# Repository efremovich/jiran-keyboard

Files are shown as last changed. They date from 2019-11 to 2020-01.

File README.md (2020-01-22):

# Jiran Keyboard
Jiran is a 6x4 matrix ergo keyboard with additional 3 thumb and 1 pinky keys. 



Based on the [Jian](https://github.com/KGOH/Jian-Info) keyboard.

* __Author:__ [t.me/ladniys](https://t.me/ladniys) [u/Ladniy](https://reddit.com/u/Ladniy)
* __Layout:__ [keyboard-layout-editor.com](http://www.keyboard-layout-editor.com/#/gists/0547cd126f61f8c3f76b0a9952901da4)
* __Hardware Availability:__ open source, t.me/ladniys
* __Firmware:__ [QMK](https://github.com/Ladniy/qmk_firmware)
* __Building guide:__ not available yet
* __Parts (BOM):__

| Name | Value | Package | Count | Optional  | Comment |
| :--- | ---: | :--- | ---: | :--- | :--- |
| Pro micro | 5V 16MHz | 17.78x33.02mm | 2 | | |
| Switch | | MX/Alps/Choc | 56 | | |
| Diode | 1N4148 | THT/SMD (SOD-123) | 56 | | |
| Resistor | 4.7k | THT/SMD (0805) | 2 | | Must be placed on the master half |
| TRRS jack | | PJ-320A | 2 | | Optional if you're building only one half  
| Tact switch | | DIP 3X6X4,3mm | 2 |  yes | |
| Mosfet | 2N7002 | SOT-123 | 2 |  yes | Optional for LED's |
| Resistor | 10k | THT/SMD (0805) | 2 |  yes | Optional for LED's |
| Resistor | 330 | THT/SMD (0805) | 56 |  yes | Optional for LED's |
| LED | | THT 1.8mm | 56 |  yes | Optional |

MechChurch (https://t.me/s/mechchurch) Supported by [MechChurch](https://t.me/s/mechchurch) community

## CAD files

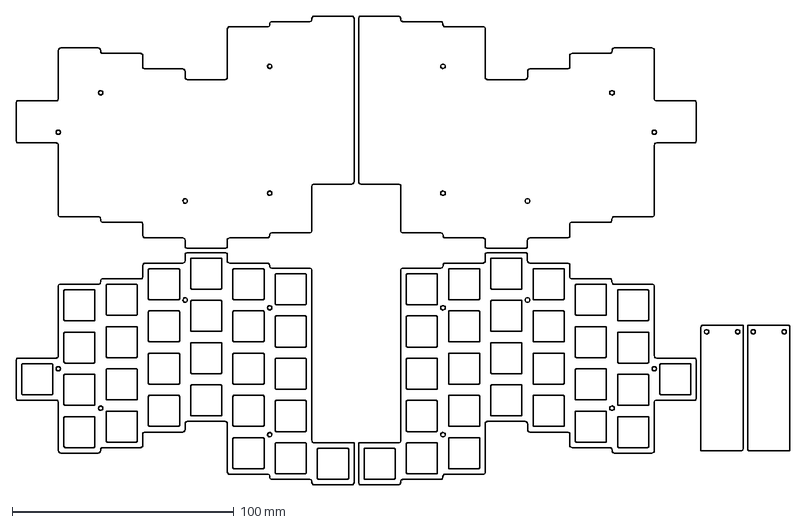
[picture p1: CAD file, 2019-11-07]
Case/Case.dxf
348.8 x 211.3 mm

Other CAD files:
Case/Case.dwg

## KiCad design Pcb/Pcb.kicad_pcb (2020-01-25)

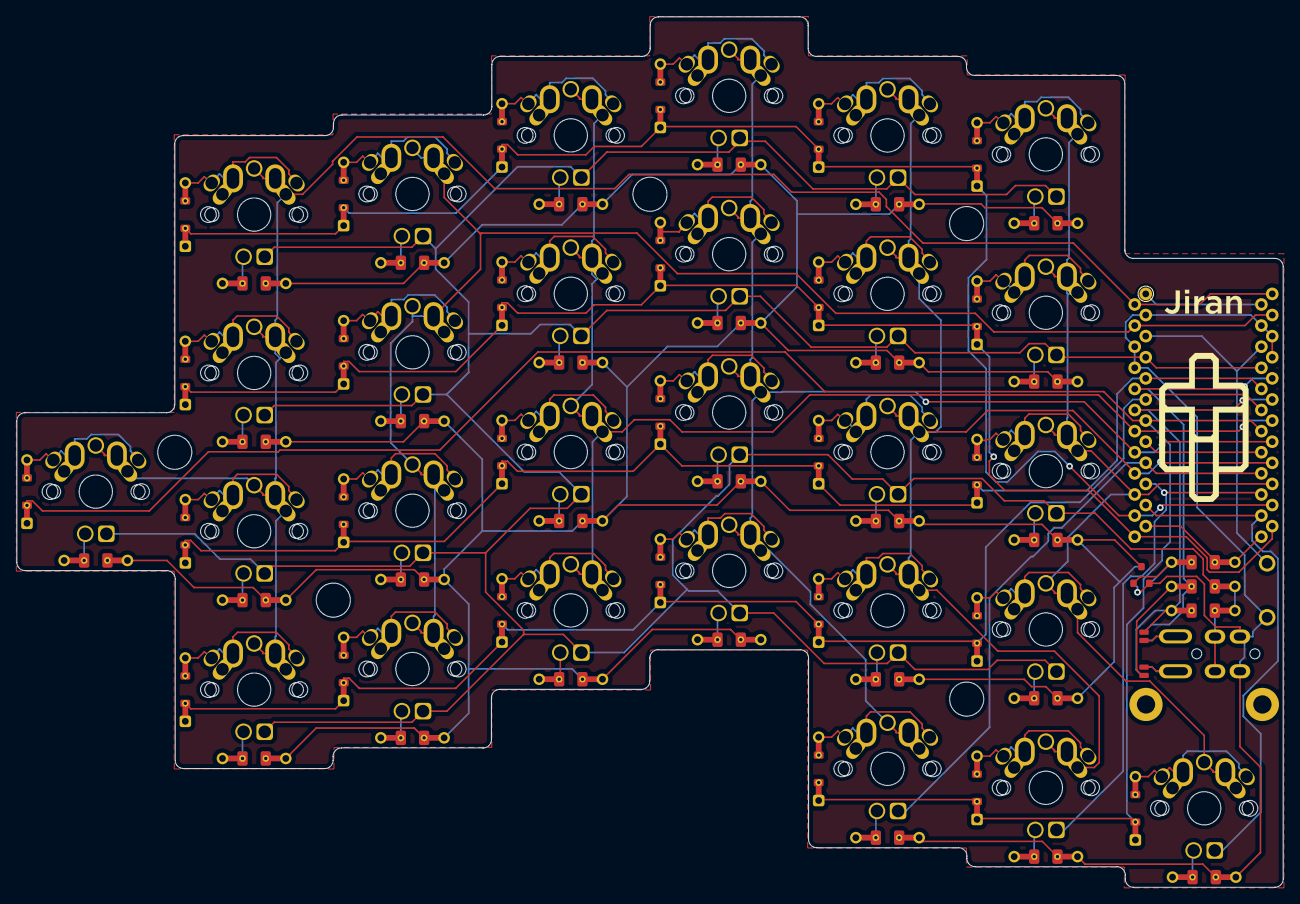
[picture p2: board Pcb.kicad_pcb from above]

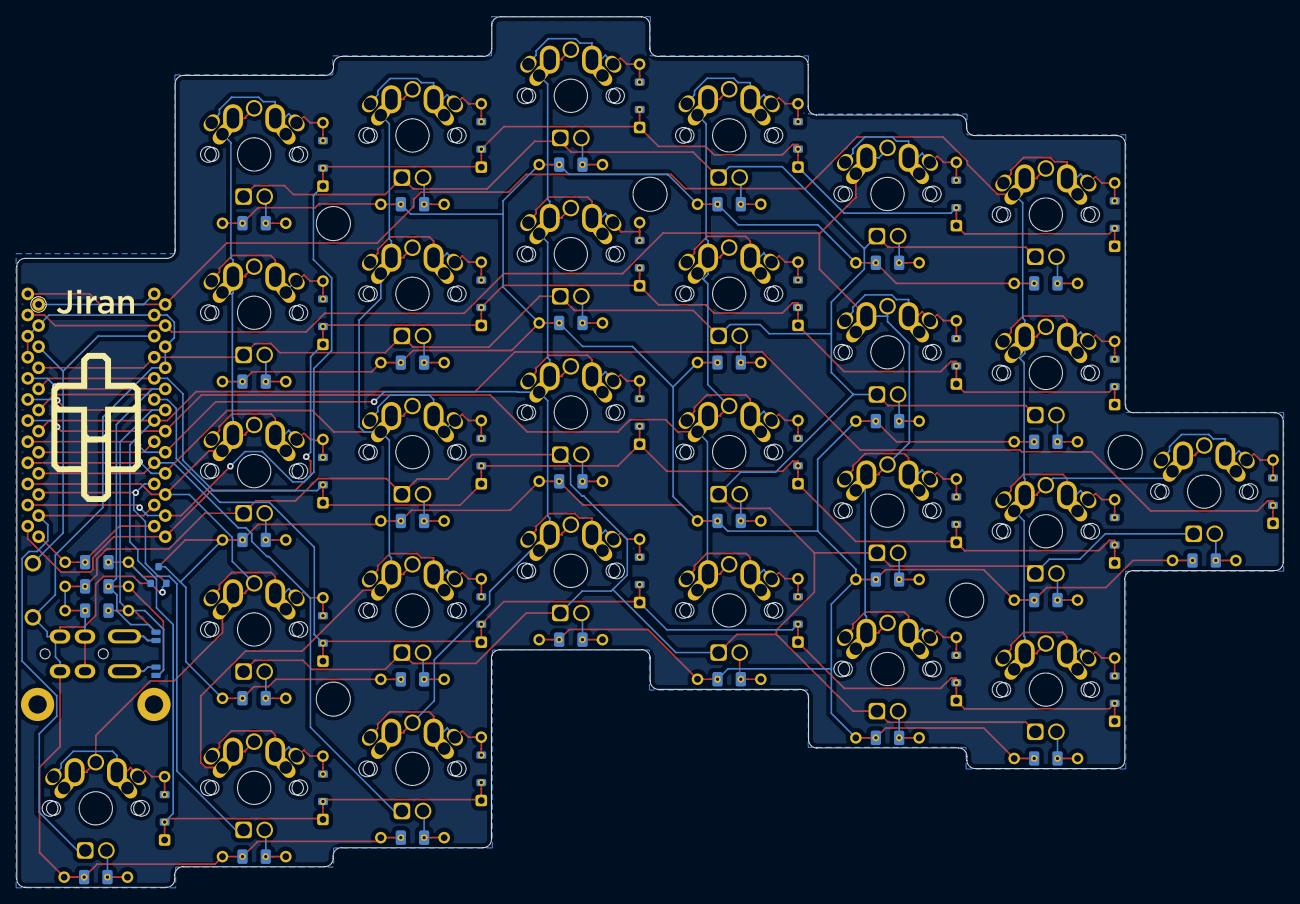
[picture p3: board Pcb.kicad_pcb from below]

Board: 2 copper layers, 152.3 x 104.7 mm, 132 parts (3 on the bottom side), 80 nets.

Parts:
D1, D2, D3, D4, D5, D6, D7, D8, D9, D10, D11, D12, D13, D14, D15, D16, D17, D18, D19, D20, D21, D22, D23, D24, D25, D26, D27, D28: 1N4148; Diode_Hybrid_SOD-123
D29, D30, D31, D32, D33, D34, D35, D36, D37, D38, D39, D40, D41, D42, D43, D44, D45, D46, D47, D48, D49, D50, D51, D52, D53, D54, D55, D56: LED_Small; LED
G1, G2: LOGO; Silk_Logo_Old
H1, H2, H3, H6, H7: CaseHole; MountHole
H8, H9: CoverHole
J1: TRRS; TRSS_DUAL_THT
JP2, JP3, JP4, JP5: Jumper; jumper
Q1: 2N7002; SOT-23
R1, R2, R3, R4, R5, R6, R7, R8, R9, R10, R11, R12, R13, R14, R15, R16, R17, R18, R19, R20, R21, R22, R23, R24, R25, R26, R27, R28: 330R; Resistor_Hybrid_1205
R29, R30: 4.7k; Resistor_Hybrid_1205
R31: 10k; Resistor_Hybrid_1205
SW1, SW3, SW4, SW5, SW6, SW7, SW8, SW9, SW10, SW11, SW12, SW13, SW14, SW15, SW16, SW17, SW18, SW19, SW20, SW21, SW22, SW23, SW24, SW25, SW26, SW27, SW28: SW_Push; Switch_MxAlpsChoc_MillMax_1u
SW2: SW2; Switch_MxAlpsChoc_MillMax_1u
SW29: SW_Push; Reset_Switch
U1: ProMicro; ProMicro_TwoSide

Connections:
/CAPS: D54.2, U1.16
/LED: R31.2, U1.13
/LEDOut: Q1.3, R1.2, R2.2, R3.2, R4.2, R5.2, R6.2, R7.2, R8.2, R9.2, R10.2, R11.2, R12.2, R13.2, R14.2, R15.2, R16.2, R17.2, R18.2, R19.2, R20.2, R21.2, R22.2, R23.2, R24.2, R25.2
/NUM: D56.2, U1.14
/SCROLL: D55.2, U1.15
/col0: SW1.2, SW7.2, SW13.2, SW19.2, SW25.2, U1.1
/col1: SW2.2, SW8.2, SW14.2, SW20.2, U1.2
/col2: SW3.2, SW9.2, SW15.2, SW21.2, U1.7
/col3: SW4.2, SW10.2, SW16.2, SW22.2, SW26.2, U1.8
/col4: SW5.2, SW11.2, SW17.2, SW23.2, SW27.2, U1.9
/col5: SW6.2, SW12.2, SW18.2, SW24.2, SW28.2, U1.10
/rowA: D1.1, D2.1, D3.1, D4.1, D5.1, D6.1, U1.11
/rowB: D7.1, D8.1, D9.1, D10.1, D11.1, D12.1, U1.12
/rowC: D13.1, D14.1, D15.1, D16.1, D17.1, D18.1, U1.20
/rowD: D19.1, D20.1, D21.1, D22.1, D23.1, D24.1, U1.19
/rowE: D25.1, D26.1, D27.1, D28.1, U1.18
GND: J1.B, Q1.2, R26.2, R27.2, R28.2, SW29.2, U1.3, U1.4, U1.23
unnamed: D1.2, SW1.1
unnamed: D2.2, SW2.1
unnamed: D3.2, SW3.1
unnamed: D4.2, SW4.1
unnamed: D5.2, SW5.1
unnamed: D6.2, SW6.1
unnamed: D7.2, SW7.1
unnamed: D8.2, SW8.1
unnamed: D9.2, SW9.1
unnamed: D10.2, SW10.1
unnamed: D11.2, SW11.1
unnamed: D12.2, SW12.1
unnamed: D13.2, SW13.1
unnamed: D14.2, SW14.1
unnamed: D15.2, SW15.1
unnamed: D16.2, SW16.1
unnamed: D17.2, SW17.1
unnamed: D18.2, SW18.1
unnamed: D19.2, SW19.1
unnamed: D20.2, SW20.1
unnamed: D21.2, SW21.1
unnamed: D22.2, SW22.1
unnamed: D23.2, SW23.1
unnamed: D24.2, SW24.1
unnamed: D25.2, SW25.1
unnamed: D26.2, SW26.1
unnamed: D27.2, SW27.1
unnamed: D28.2, SW28.1
unnamed: D29.1, R1.1
unnamed: D30.1, R2.1
unnamed: D31.1, R3.1
unnamed: D32.1, R4.1
unnamed: D33.1, R5.1
unnamed: D34.1, R6.1
unnamed: D35.1, R7.1
unnamed: D36.1, R8.1
unnamed: D37.1, R9.1
unnamed: D38.1, R10.1
unnamed: D39.1, R11.1
unnamed: D40.1, R12.1
unnamed: D41.1, R13.1
unnamed: D42.1, R14.1
unnamed: D43.1, R15.1
unnamed: D44.1, R16.1
unnamed: D45.1, R17.1
unnamed: D46.1, R18.1
unnamed: D47.1, R19.1
unnamed: D48.1, R20.1
unnamed: D49.1, R21.1
unnamed: D50.1, R22.1
unnamed: D51.1, R23.1
unnamed: D52.1, R24.1
unnamed: D53.1, R25.1
unnamed: D54.1, R26.1
unnamed: D55.1, R27.1
unnamed: D56.1, R28.1
unnamed: J1.A, JP2.1, JP3.1
unnamed: J1.D, JP4.1, JP5.1
unnamed: Q1.1, R31.1
RST: SW29.1, U1.22
SCL: JP3.2, JP5.2, R30.2, U1.6
SDA: JP2.2, JP4.2, R29.1, U1.5
VCC: D29.2, D30.2, D31.2, D32.2, D33.2, D34.2, D35.2, D36.2, D37.2, D38.2, D39.2, D40.2, D41.2, D42.2, D43.2, D44.2, D45.2, D46.2, D47.2, D48.2, D49.2, D50.2, D51.2, D52.2, D53.2, J1.C, R29.2, R30.1, U1.21

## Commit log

2019-10-19 Initialize project
    [Pcb.kicad_pcb, Pcb.sch]
2019-10-19 Finished with schematic and footprints
2019-10-19 Started work on pcb
    [Plate.dwg, Plate.dxf]
2019-10-19 PCB update
    [Pcb.kicad_pcb, Plate.dxf]
2019-10-19 PCB route complete
    [Pcb.dsn, Pcb.kicad_pcb]
2019-10-19 Postrout optimization
    [Pcb.kicad_pcb]
2019-10-20 Little Update
    Added hole's for mount, fixed some problems and created 3D design.
    [Plate.dxf]
2019-10-20 Create a 3D case model.
    [Left Case.step]
2019-10-20 Adapted for 3D print case.
    [Pcb.dsn, Pcb.kicad_pcb]
2019-10-21 Adapted for 3D case.
    [Pcb.kicad_pcb]
2019-10-22 Addapted for 3D case
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2019-10-23 Updated Silkscreen
    [Pcb.kicad_pcb]
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2019-10-24 Created gerber files
    [Pcb-B_Cu.gbl, Pcb-B_Mask.gbs, Pcb-B_SilkS.gbo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]
2019-10-24 Created ZIP archive with gerbers
2019-10-26 Created 3D case
    [CaseLeft.step, CaseRight.step, Left Case.step]
2019-10-26 Added file for lasercut for case part
    [UnderPlate.dwg]
2019-10-26 Added file for laser cut for case part
    [UnderPlate.dxf]
2019-10-26 Created and fixed file for laser cut of acrylic case
    [Plate.dwg, Plate.dxf]
2019-10-27 Added STL files for 3D print
    [CaseLeft.stl, CaseRight.stl]
2019-10-27 Removed Tracks
    [Pcb.kicad_pcb]
2019-10-27 Move dot's for other footprints
2019-10-27 Leds was rotated to north side
    [Pcb.kicad_pcb]
2019-10-27 Edited silkscreen
    [Pcb.kicad_pcb]
2019-10-27 Created new name silkscreen
2019-10-27 Created silkscreen for resistors value
2019-10-27 Removed silkscreen for rasistor value
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2019-10-27 Routed and filled
    [Pcb.kicad_pcb]
2019-10-27 Removed old gerbers
    [Pcb-B_Cu.gbl, Pcb-B_Mask.gbs, Pcb-B_SilkS.gbo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]
2019-10-27 Added new gerbers
    [Pcb-B_Cu.gbl, Pcb-B_Mask.gbs, Pcb-B_SilkS.gbo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]
2019-11-02 Fixed bug with I2C resistor's
    [Pcb.sch]
2019-11-02 Unfill zones
    [Pcb.kicad_pcb]
2019-11-02 Deleted track's
    [Pcb.kicad_pcb]
2019-11-02 Moved diode
    [Pcb.kicad_pcb]
2019-11-02 Added support for Choc and Apls switche's
    [Pcb.kicad_pcb]
2019-11-03 Deleted ISP header
    [Pcb.sch]
2019-11-03 Added LED's for lock indication
    [Pcb.sch]
2019-11-03 Changed I2C jack
    [Pcb.sch]
2019-11-03 Updated footprints
    [Pcb.sch]
2019-11-03 Moved some parts
    [Pcb.kicad_pcb]
2019-11-04 Added hole's
    [Pcb.sch]
2019-11-04 Placed hole in correct position
    [Pcb.sch]
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2019-11-04 Update
    Deleted silkscreen, moved jumpers and some components
    [Pcb.kicad_pcb]
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2019-11-04 Redesigned case
    [Plate.dwg, Plate.dxf]
2019-11-04 Created case for Jian mode
    [Plate.dwg, Plate.dxf]
2019-11-04 Update
    Added tracks, edited silkscreen etc.
    [Pcb.kicad_pcb]
2019-11-04 Updated design for both mode
    [Plate.dwg, Plate.dxf]
2019-11-05 Removed catalog with 3D print
    [CaseLeft.step, CaseLeft.stl, CaseRight.step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]
2019-11-05 Unfill all zones
    [Pcb.kicad_pcb]
2019-11-05 Updated jumper footprint
    [Pcb.kicad_pcb]
2019-11-05 Fill all zones
    [Pcb.kicad_pcb]
2019-11-05 Created new gerbers
    [Pcb-B_Cu.gbl, Pcb-B_Mask.gbs, Pcb-B_SilkS.gbo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]
2019-11-06 Import SES file
    [Pcb.kicad_pcb]
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2019-11-09 Update mosfet footprint
    [Pcb.kicad_pcb]
2019-11-09 Add holes for breakway numrow
    [Pcb.kicad_pcb]
2019-11-09 Remove old gerber
    [Pcb-B_Cu.gbl, Pcb-B_Mask.gbs, Pcb-B_SilkS.gbo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]
2019-11-09 Remove old silkscreen footprint
2019-11-09 Add new silkscreen
    [Pcb.kicad_pcb]
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2019-11-10 Route PCB
    [Pcb.dsn, Pcb.kicad_pcb]
2019-11-10 Place track and fill all zones
    [Pcb.kicad_pcb]
2019-11-12 Create gerber files
    [Pcb-B_Cu.gbl, Pcb-B_Mask.gbs, Pcb-B_SilkS.gbo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]
2019-11-12 Add JLC silkscreen mark
    [Pcb.kicad_pcb]
2019-11-12 Move JLC silkscreen mark
    [Pcb.kicad_pcb]
2019-11-12 Create new gerbers files
    [Pcb-B_Cu.gbl, Pcb-B_Mask.gbs, Pcb-B_SilkS.gbo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]
2019-11-12 Create ZIP archive with gerbers
2019-11-13 Add CDR file for Jiran mode case
2019-12-16 Add CDR format file for Jian's mod case
    [Plate_recover.dwg]
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2019-12-18 Update hole footprints
    [Pcb.kicad_pcb]
2019-12-18 Add more break holes
    [Pcb.kicad_pcb]
2019-12-18 Update dsn file for new hole size
    [Pcb.dsn]
2019-12-18 Remove old logo silkscreen
    [Pcb.kicad_pcb]
2019-12-18 Remove hole for Jian mode
    [Pcb.kicad_pcb]
2019-12-18 Move hole for mount
    [Pcb.dsn, Pcb.kicad_pcb]
2019-12-18 Route tracks
    [Pcb.kicad_pcb]
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2019-12-19 Move SOT
    [Pcb.kicad_pcb]
2019-12-19 Move pro micro footprint
    [Pcb.kicad_pcb]
2019-12-20 Update
    Remove old render, edit description, add building and BOM titles
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2019-12-20 Add support millmax socket for swithes
    [Pcb.kicad_pcb, Pcb.sch]
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2019-12-20 Change hole size for spacer
    [Pcb.kicad_pcb]
2019-12-20 Route track
    [Pcb.dsn, Pcb.kicad_pcb]
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2019-12-20 Remove old gerbers
    [Pcb-B_Cu.gbl, Pcb-B_Mask.gbs, Pcb-B_SilkS.gbo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]
2019-12-20 Remove Jian case version
    [Plate.dwg, Plate.dxf]
2019-12-20 Create new gerbers file
    [Pcb-B_Cu.gbl, Pcb-B_Mask.gbs, Pcb-B_SilkS.gbo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]
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2020-01-22 Replace footprints
    [Pcb.kicad_pcb, Pcb.sch]
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2020-01-22 Replace TRRS footprint
    [Pcb.kicad_pcb]
2020-01-22 Remove old version
    [Plate.dwg, Plate.dxf]
2020-01-22 Create new gerbers for old silkscreen
    [Pcb-B_Cu.gbl, Pcb-B_Mask.gbs, Pcb-B_SilkS.gbo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]
2020-01-22 Remove old gerber files
    [Pcb-B_Cu.gbl, Pcb-B_Mask.gbs, Pcb-B_SilkS.gbo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]
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2020-01-22 Replace silk
    [Pcb.kicad_pcb]
2020-01-25 Add corect value of diode
    [Pcb.kicad_pcb]
2020-01-25 Add corect value of resistors
    [Pcb.kicad_pcb]
2020-01-25 Add interactive BOM file for build
    [Pcb.kicad_pcb]
